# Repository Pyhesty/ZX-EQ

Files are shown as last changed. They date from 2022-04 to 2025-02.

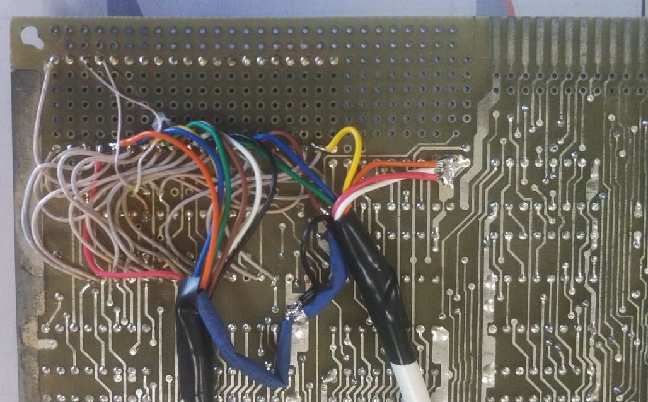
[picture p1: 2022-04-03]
Photo/ZXeq_ScorpAssembly_AM.jpg

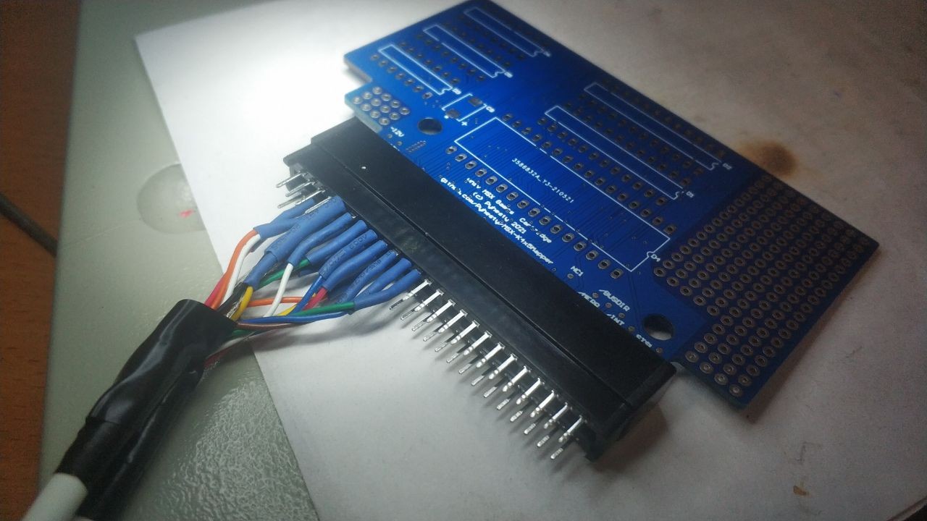
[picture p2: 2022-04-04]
Photo/SlotAssembly_photo1.jpg

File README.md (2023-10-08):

# ZX-EQ
март 2023 
версия ZX-EQ оформлена группой RBSC =)
https://github.com/RBSC/ZX-EQ
отличий между версией представленной здесь и на RBSC быть не должно
RBSC версия проверена и не предполагается к изменениям, а на своём гитхабе могу вноситель небольшие дополнения
отмечу, что добавлена плата кросса, которая позволяет удобно установить плату в стандартный разъём ZX-BUS

ранее из описания:

работа над проектом продолжается при наличии времени,
со временем все файлы проекта будут доступны здесь, сердцем платы является PLD EPM7128STC-100.
Файлы проекта нельзя использовать для коммерчесского использования без согласования с автором, только и исключительно для личного пользования

Проект не для коммерческого использования.

Предоставляется всю информация и файлы бесплатно, без каких-либо обязательств или гарантий. Предоставленная информация и (или) файлы не могут быть использованы в коммерческих целях без согласования с автором проекта. Изготовление нескольких плат картриджа для себя или друзей не возбраняется. Продажа остатков партии несобранных плат также разрешена без каких-либо выплат авторам.

# PS
если у вас есть микросхема EPM7128STC-100 (TSOP-100 квадратный корпус) и светодиоды (72 штуки) 
и вы хотите собрать для себя плату - напишите мне в личку после 30 апреля, жду платы с фабрики - поделюсь.
почта: pyhesty@gmail.com (с темой ZX-EQ)

update 10/04/22:
мне, наконец, удалось заказать PLD для плат и я очень надеюсь, что придёт то, что я заказал, к сожалению канал поставки не надежный..., если вы готовы самостоятелньо интегрировать плату ZX-EQ к своему ZX, то пишите на почту, сможем договориться, я вам вышлю один из вариантов:
1. плата с установленной PLD, но без диодов, что бы вы могли самостоятельно собрать свой цвет или набор цветов
2. плату с PLD и дискретными диодами: синий или синий(5)+красный(3), другие варианты по наличию у меня диодов, их, к сожалению, нужно очень много

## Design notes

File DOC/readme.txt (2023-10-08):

--------------------------------------------------------------------------------
ZX-EQ PSG Spectrolyzer
Copyright (c) 2023 RBSC
Developer: Pyhesty
Last update: 15.03.2023
--------------------------------------------------------------------------------

About the project
-----------------

The ZX-EQ PSG Spectrolyzer is a simple cartridge for the ZX platform that visualizes the spectrum of notes played by the
programmable sound generator, such as the AY-3-8910 or YM2149 (PSG). The cartridge board is intended for the standard ZX
cartridge slot. The board shows the effect of measuring the signal's level, in which each reproduced frequency (or frequency
range) corresponds to one of 9 vertical LED indicators.

All files of the ZX-EQ project are available in the RBSC's Github repository: 

 - https://github.com/RBSC/ZX-EQ

Hardware
--------
 
The ZX-EQ cartridge is based on the PLD Altera EPM7128, that has 128 logical units. The PLD intercepts PSG port I/O, identifies
the played note/frequency and displays its representation on the dedicated LED indicator. The cartridge doesn't need any special
setup. It can be installed into any standard ZX slot that allows an unobstructed view of the cartridge's LED indicators.

The cartridge visualizes the played notes/frequencies in games and demos in real time. After a note/frequency fades out, the LED
indicators automatically switch off.

The cartridge may be assembled in 2 different ways:

 - With discrete LED elements - simple, but allowing various color combinations
 - With LED assemblies - the so-called "bars", mostly single-colored

The following color combinations are possible (those were tested and were found suitable for the project, however other color
combinations are possible):

 - One color LEDs or LED assemblies: blue, red or green
 - Multi-colored LEDs or LED assemblies: blue with red or green with red (red LEDs are placed on top)

Firmware uploading
------------------

The freshly-assembled ZX-EQ cartridge needs the firmware to be uploaded into the PLD chip. For updating/uploading the firmware
into the cartridge you will need:

 - Quartus II Web Edition (Free) v15.0 or later software
 - Byte Blaster or USB Blaster programmer (can be purchased on Ebay or AliExpress)

The procedure is simple - supply 5v onto the cartridge board, connect the USB Blaster to the JTAG connector's placeholder (mind
the orientation of the connector!). Auto-detect the Altera chip with Quatrus software and then upload the POF file from the
"Firmware" folder into the PLD chip.

The Quartus Programmer software can be downloaded from here:

 - https://mirrors.pdp-11.ru/_ZX/_carnivore2/quartus/

Assembling notes
----------------

It's highly recommended to install all ceramic capacitors (100nF) onto the board. In addition, at least one tantalum capacitor should
be installed.

Cartridge case
--------------

Any factory-made ZX cartridge manufactured from semi-transparent or transparent plastic is suitable for the ZX-EQ cartridge board.
For example, the following quality ZX cartridge cases can be obtained from Overrich (South Korea) and Retro Game Restore (Taiwan):

 - https://retrogamerestore.com/store/ZX_cart_shell/
 - https://www.ZX.org/news/en/black-white-and-transparent-ZX-cartidge-cases-overrich

Also, there's a 3D model of the cartridge case in the repository. The case should be printed with semi-transparent filament.

Where to buy parts
------------------

All parts for assembling the ZX-Eq cartridge can be purchased from varios sellers on AliExpress:

1. PLD: EPM7128STC100
2. LEDs: single 0805 size LEDs or LED assemblies
3. Resistors: 0805 1k
4. Capacitors: 0805 0.1uF
5. Tantalum capacitors: TypeB or TypeC, 10-100uF
6. Edge slot: ISA-50 or ISA-56 Slot 

See the partslist.txt document for more info.

Visual Effects
--------------

You can check how the cartridge visualizes various PSG effects by watching these videos:

 - Demo 1: https://youtu.be/9qOor28YGpI
 - Demo 2: https://youtu.be/czu8WWsEIOM
 - Demo 3: https://youtu.be/p7G4cLf7g2w

IMPORTANT!
----------

The RBSC provides all the files and information for free, without any liability (see the disclaimer.txt file). The provided information,
software or hardware must not be used for commercial purposes unless permitted by the RBSC. Producing a small amount of bare boards for
personal projects and selling the rest of the batch is allowed without the permission of RBSC.

When the sources of the tools are used to create alternative projects, please always mention the original source and the copyright!

If you would like to commercially produce this cartridge, please contact the administrator of the RBSC (see info below).

Contact information
-------------------

The members of RBSC group Tnt23, Wierzbowsky, Pyhesty, Ptero, GreyWolf, SuperMax, VWarlock and DJS3000 can be contacted via the group's e-mail
address:

info@rbsc.su

The group's coordinator could be reached via this e-mail address:

admin@rbsc.su

The group's website can be found here:

https://rbsc.su/
https://rbsc.su/ru

The RBSC's hardware repository can be found here:

https://github.com/rbsc

The RBSC's 3D model repository can be found here:

https://www.thingiverse.com/groups/rbsc/things

-= ! Z80 FOREVER ! =-

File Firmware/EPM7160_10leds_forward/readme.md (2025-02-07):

Версия программы PLD для EPM7160
1. Поддержка 10 диодов
2. Монтаж диодов: прямой (в соответствии со схемой)
3. Порядок диодов: прямой, снизу вверх
-----
в каталоге:
1. Файл программы для PLD EPM71606: epm7160-leds-right__upper.pof
2. Исходный код программы: epm7160-leds-right__upper.tdf
   
Отдельная благодарность ZCasper за сборку первого устройства, первый запуск и проверку ZX-EQ в такой конфигурации

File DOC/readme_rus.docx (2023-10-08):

ZX-EQ PSG Spectrolyzer для платформы ZX Spectrum

Разработчик: Pyhesty [RBSC]. Copyright (C) 2023

Для получения дополнительной информации мы рекомендуем прочитать английский readme.txt файл из репозитория

О проекте

ZX-EQ PSG Spectrolyzer – это простое устройство визуализатор спектра нот, воспроизводимых программируемым звуковым генератором типа AY-3-8910 или YM2149 (PSG). Плата предназначена для установки в стандартный ISA слот в плате расширения ZX-Cross. Плата воспроизводит эффект измерения уровня сигнала, при котором каждой воспроизводимой частоте (диапазону частот) соответствует один из девяти вертикальных светодиодных индикаторов. После воспроизведения ноты или частоты индикатор плавно затухает.

Возможны две версии исполнения картриджа:

1. На дискретных светодиодных элементах; более простая, но позволяющая реализовать различные цветовые решения
2. На светодиодных сборках, так называемых "bar", в большинстве своём одноцветных

Возможны следующие цветовые решения, которые были нами опробованы и дали хороший визуальный эффект (также возможны и другие цветовые решения):

1. Одноцветные светодиоды или светодиодные сборки синего, красного или зелёного цветов
2. Многоцветные светодиодные сборки или комбинации отдельных светодиодов: синего с красным или зеленого с красным (красные светодиоды размещаюся сверху)

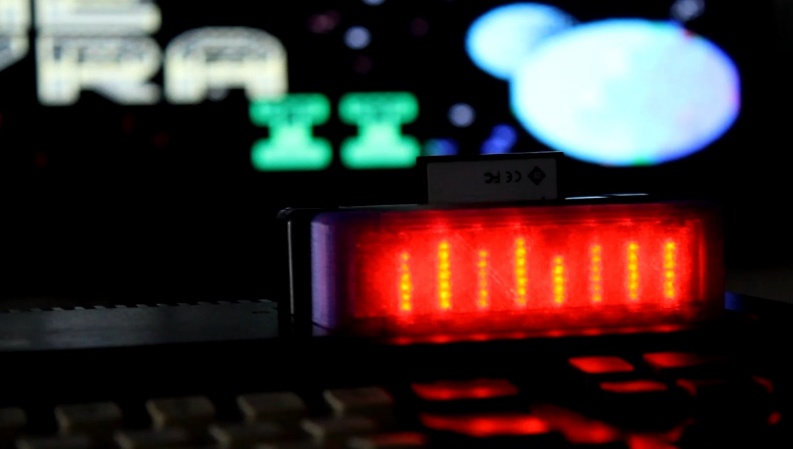
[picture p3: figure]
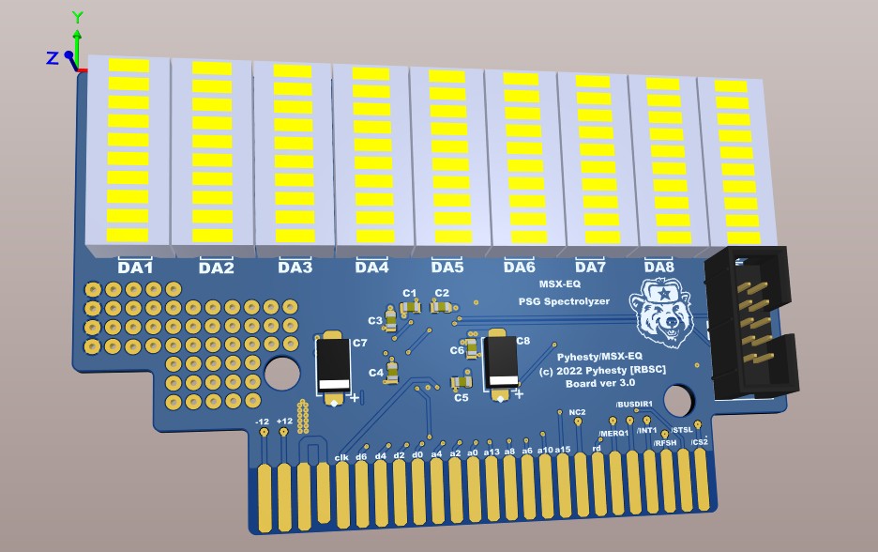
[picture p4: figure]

Картридж ZX-EQ создан на базе PLD Altera EPM7128, состоящей из 128 логических блоков и регистров. PLD анализирует запись в порты звукового генератора, вычисляет соответствующую ноту (частоту) и визуализирует её на соответствующем светодиодном индикаторе.

Устройство не требует никаких дополнительных настроек. В ZX Spectrum устанавливается вначале плата ZX-Cross, после неё необходимо установить плату ZX-EQ, что позволяет иметь хороший обзор верхней передней части картриджа (там расположены индикаторы). При проигрывании музыки, например в играх или демонстрационных программах, картридж в режиме реального времени визуализирует спектр используемых частот (нот). После завершения музыкальной композиции индикаторы гаснут автоматически.

В качестве корпуса для ZX-EQ подходит любой промышленно выпускаемый полупрозрачный корпус для MSX картриджа, например корпус от Retro Game Restore или от Overrich:

- https://retrogamerestore.com/store/msx_cart_shell/
- https://www.msx.org/news/en/black-white-and-transparent-msx-cartidge-cases-overrich

Для этого картриджа также подходит корпус из полупрозрачного пластика, распечатанный на 3Д принтере. Модель можно найти в репозитории.

Демонстрацию работы картриджа можно посмотреть здесь:

- Demo 1: https://youtu.be/9qOor28YGpI
- Demo 2: https://youtu.be/czu8WWsEIOM
- Demo 3: https://youtu.be/p7G4cLf7g2w

Все файлы проекта ZX-EQ доступны для некоммерческого использования в репозитории группы RBSC по этому адресу:

- https://github.com/RBSC/ZX-EQ

По вопросам коммерческого использования или изготовления картриджа необходимо обратиться к администратору группы RBSC (см. ниже).

ВАЖНО!!

Группа RBSC предоставляет всю информацию и файлы бесплатно, без каких-либо обязательств или гарантий. Предоставленная информация и (или) файлы не могут быть использованы в коммерческих целях без согласования с автором проекта. Изготовление нескольких плат картриджа для себя или друзей не возбраняется. Продажа остатков партии несобранных плат также разрешена без каких-либо выплат авторам.

Как с нами связаться

С членами группы RBSC - Tnt23, Wierzbowsky, Pyhesty, Ptero, GreyWolf, SuperMax и DJS3000 можно связаться по этому адресу электронной почты: info@rbsc.su

С координатором группы RBSC, например по вопросам коммерческого использования проектов группы, можно связаться по этому адресу электронной почты: admin@rbsc.su

Официальный вебсайт группы RBSC находится по этому адресу:

- https://rbsc.su/
- https://rbsc.su/ru (русская версия)

Официальный репозиторий проектов группы RBSC находится по этому адресу:

- https://github.com/rbsc

Репозиторий 3Д моделей группы RBSC находится по этому адресу:

- https://www.thingiverse.com/groups/rbsc/things

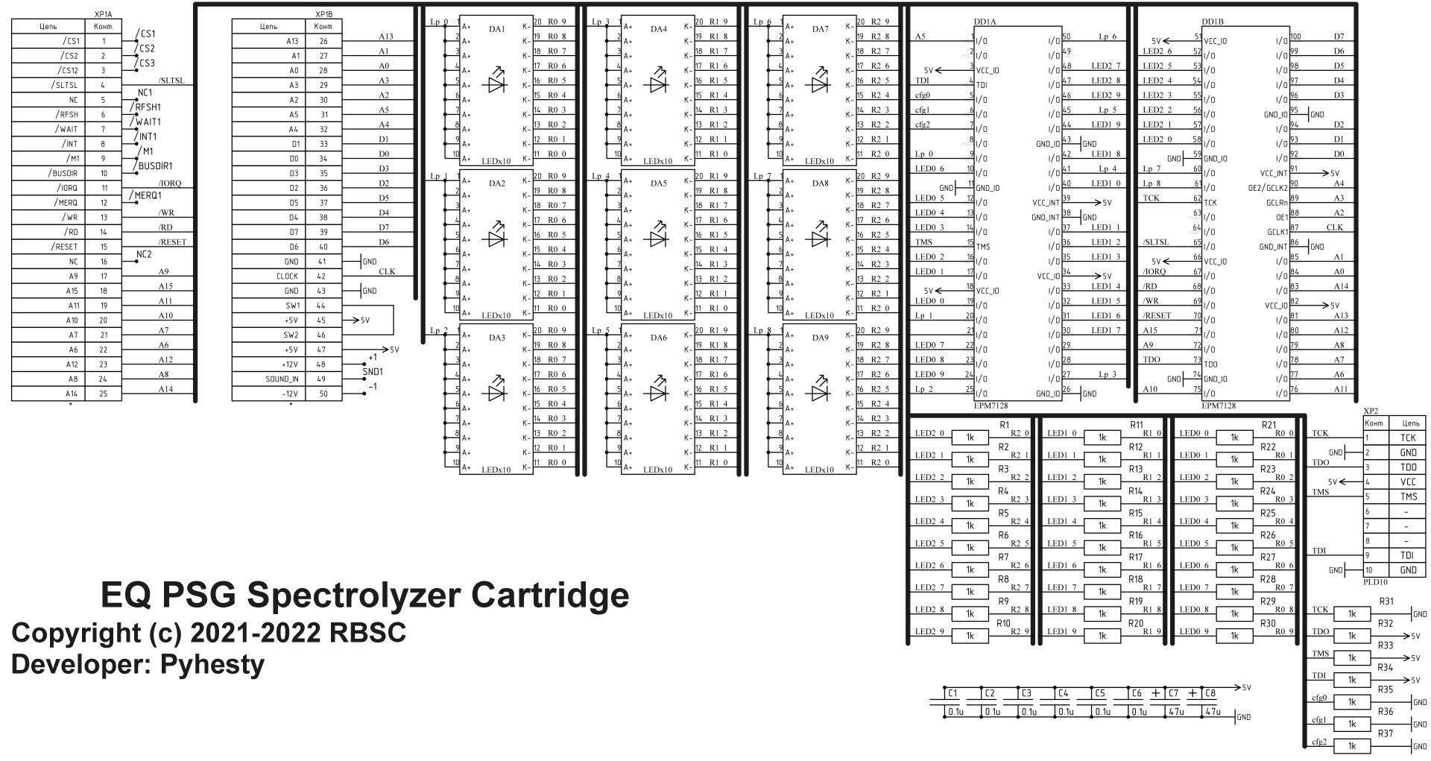
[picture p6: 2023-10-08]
DOC/zx-eq-schematics.jpg

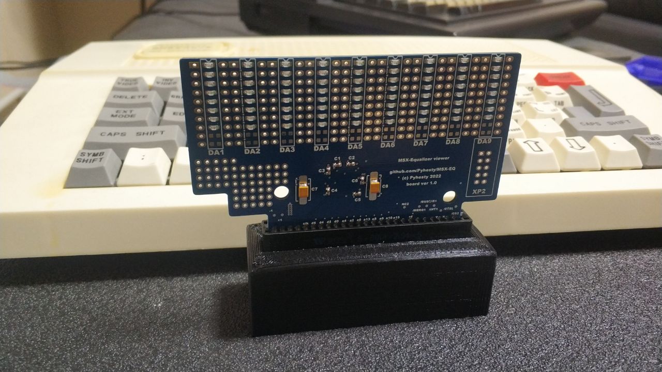
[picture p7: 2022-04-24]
Photo/ZXeq_in_stand.jpg

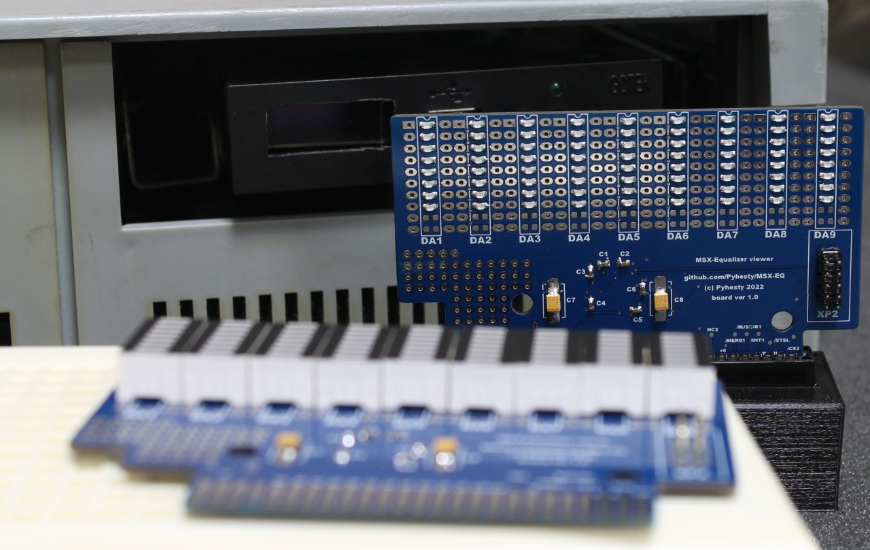
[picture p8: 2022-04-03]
Photo/ZXeq_photo1.jpg

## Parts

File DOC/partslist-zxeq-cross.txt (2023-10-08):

--------------------------------------------------------------------------------
ZX-CROSS for PSG Spectrolyzer 
Copyright (c) 2023 RBSC
--------------------------------------------------------------------------------

Partlist
--------

Part     Value           Device               Package      Library         Count
--------------------------------------------------------------------------------
X1                       ISA-50               50-pin slot                  1
X2                       ISA-56               56-pin slot                  1
X3       ZXSLOT          EDGE-CONNECTOR       62-pin slot                  1

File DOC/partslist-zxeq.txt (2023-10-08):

--------------------------------------------------------------------------------
ZX-EQ PSG Spectrolyzer
Copyright (c) 2023 RBSC
--------------------------------------------------------------------------------

Partlist
--------

Part     Value           Device               Package      Library         Count
--------------------------------------------------------------------------------
C1..C6   100nF           C-EUC0805            C0805        rcl             6
C7..C8   47uF 10v        CPOL-EUSMCB          SMC_B        rcl             2
DA1..DA9   LEDs          2010BB               DIP-8                        9
D1         PDL           EPM7128STC100        TSOP-100     IC              1
R1..R37  1k              R-EU_R0805           R0805        resistor        37
XP2      PIN-10          PLD10                             XP              1   
SLOT 	                 EDGE-CONNECTOR                    50-pin slot     1

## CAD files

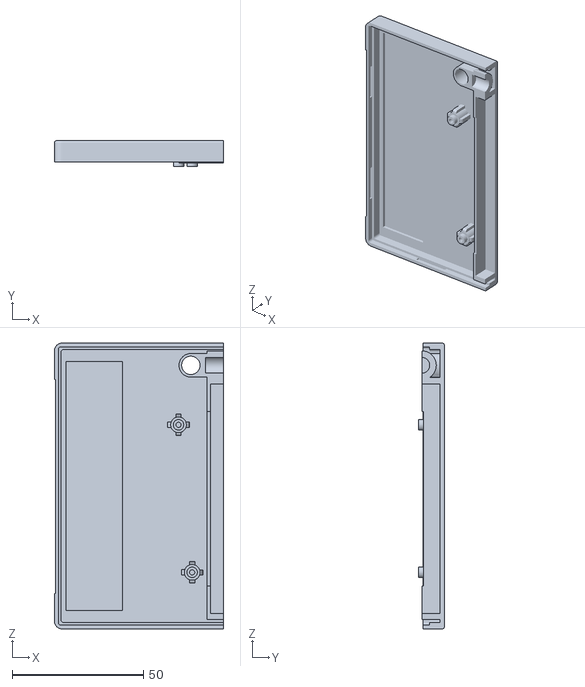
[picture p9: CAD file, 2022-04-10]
Case/ZXeqCaseTop.STL
64.5 x 9.95 x 109.0

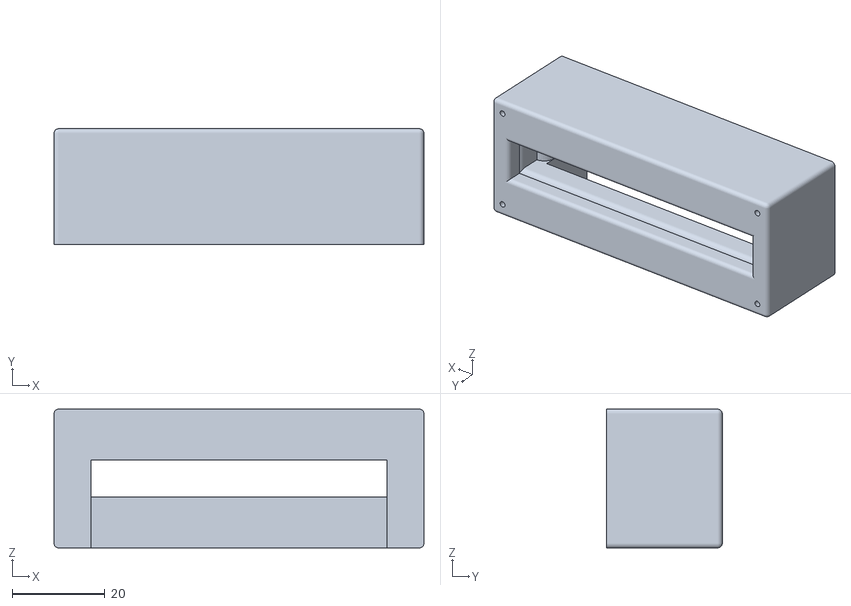
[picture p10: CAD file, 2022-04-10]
Case/ZXStand_mini_round.STL
80.0 x 25.0 x 30.0

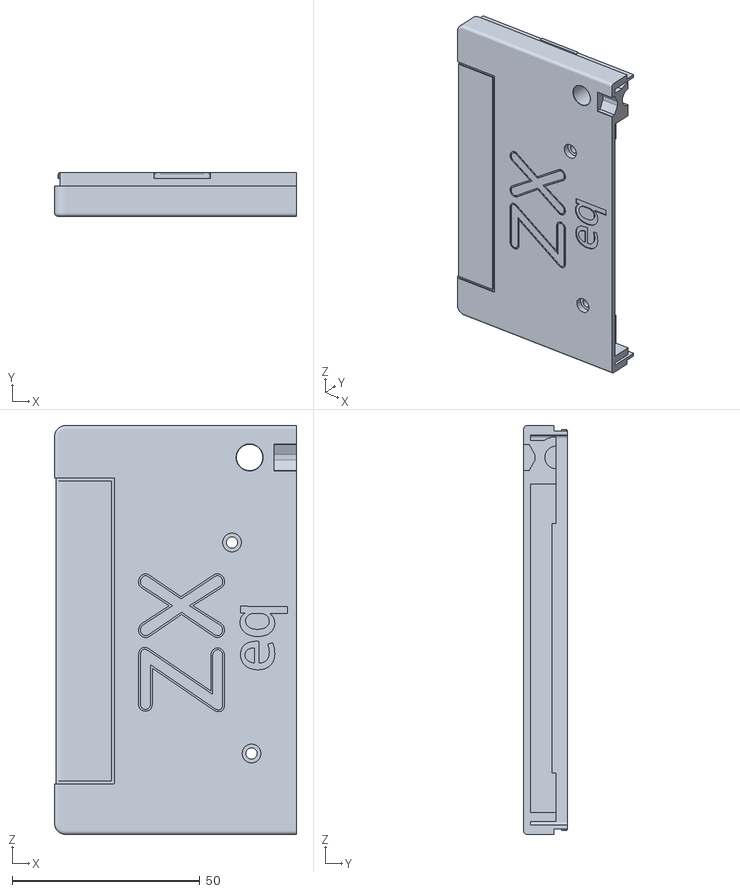
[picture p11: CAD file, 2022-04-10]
Case/ZXeqCaseBot.STL
64.5 x 11.6 x 109.0
